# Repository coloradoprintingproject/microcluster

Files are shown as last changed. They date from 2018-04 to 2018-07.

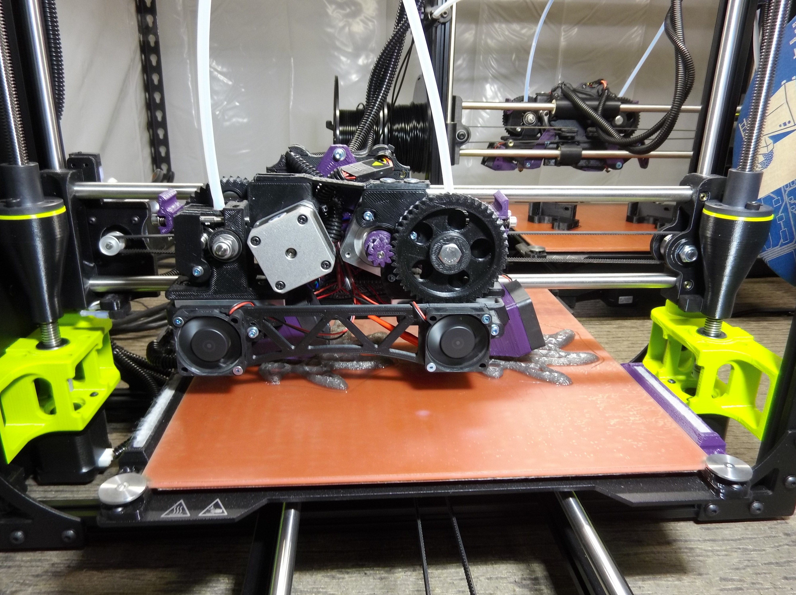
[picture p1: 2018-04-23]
photo/IMG_20180102_165738482.jpg

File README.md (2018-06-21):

This is an obsolete repo for the microcluster project by the Colorado Printing Project, as current development has been moved to notabug.org following the buyout of guthub by microsoft. Unfortunately Github doesn't have a way to make this a mirrior for the active development repo, so please visit https://notabug.org/coloradoprintingproject/microcluster for up to date source.

Everything in this repo is licensed under the GNU GPL v3.0 or CC-BY-SA 4.0.

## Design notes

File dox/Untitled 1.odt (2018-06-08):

The microcluster kit is the easiest way to build up a fitting home for your hard working 3D printers. It is both affordable and highly modular, guaranteeing that you’ll be able to build a 3D printer enclosure that meets your needs without breaking the bank.

While there are lost of printer enclosures currently on the market, you’re pretty much on your own if you want to build a multiple printer enclosure system. Now with the microcluster kit, you can easily build the perfect enclosure system to suit your needs.

Overview:

The microcluster kit system transforms a commonly available shelf into a purpose build, smart enclosure system for 2-6 desktop 3D printers. The modular upgrade system makes it easy to add lights, smart wireless control or even a photo booth setup for professional product photogarphy.

If your current “enclosure” includes cardboard or bubblewrap, it’s time for an upgrade…

The microcluster kit isn’t for everyone. If you’ve only got one printer and are content to stick to PLA printing, you will be able to get along fine without the microcluster. The microcluster kit might be right for you if:

- you have multiple 3D printers
- you are trying to print with higher temperature materials like ABS, Polycarbonate or PEEK
- you’d like some of your desk space back
- your 3D printing has been banished to the garage or basement or any other drafty, dusty place

If this describes you, or if you’ve been thinking of building a better enclosure, read on

Use Cases

Here are just a few of the instances where the microcluster kit could be a life saver:

In house Production

Public use 3D printers

Print service

Printer aficionados

Features and Specifications:

microcluster kit, half and full stack versions:

- Lightweight corrugated polyurethane panels provide excellent thermal insulation and give a professional look to your printer cluster
- Magnetic panel attachment makes the microcluster fast and easy to assemble
- PETG front doors allow you to monitor your print while keeping the enclosure well insulated
- Sliding door setup maximizes space and minimizes drafts when the doors are opened
- Half stack version encloses 24ft^3 of printer space, enough for 1 TAZ and 1 mini or up to 4 LulzBot minis.
- Full stack version encloses 48ft^3 of printer space, enough for 3 TAZ and 3 minis or up to 6 LulzBot minis.

Modular upgrades:

- Lit-kit
  - Easily installs within 5 minutes
  - RGB LED light strip allows color coding of printers, and can be interfaced with may printers as a status indicator
  - Allows for clear webcam monitoring even in a dark room
- Printed Part kit
  - If you’re using the recommended Edsal shelf as a base, this printed part kit will save you upwards of 100hrs of print time for the sliding mechanism
  - designed to print using 0 infill and spiral vase mode, these printed parts maximize any printers efficiency
  - Parts proudly printed out of high quality PLA at our factory in Sheridan, Colorado, USA.
- Octopanel
  - Easy to install and set up, the Octopanel allows you to set up wireless control of your printers withing minutes
  - Designed to work with any desktop printer
  - A portion of every octopanel purchase will go towards funding Octoprint, the open source project making this technology affordable and accessible.
  - The included logitech webcam allows constant monitoring of printing as well as the ability to take timelapses of individual prints.
  - The Octoprint system allows authorized users to access the printers, upload print jobs and monitor them remotely from any web connected device.
- Photo Booth kit
  - Fast and easy to set up, the photo booth kit makes it easy to take professional photographs of you 3D printed products

Documentation & Sources

As with all Colorado Printing Project designs everything is, has been and will continue to be fully open source. All applicable materials are available here: www.github.com/coloradoprintingproject/microcluster

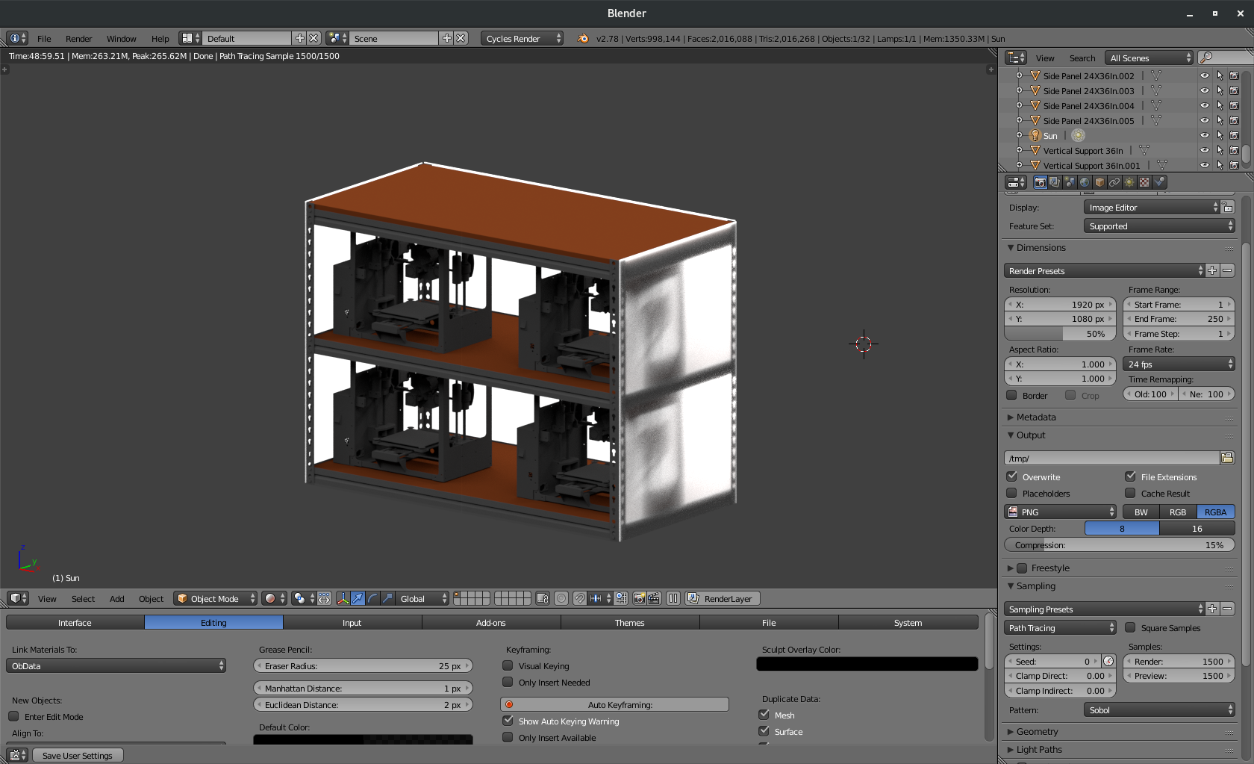
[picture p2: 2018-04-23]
photo/quardaminiclusterunitthing.png

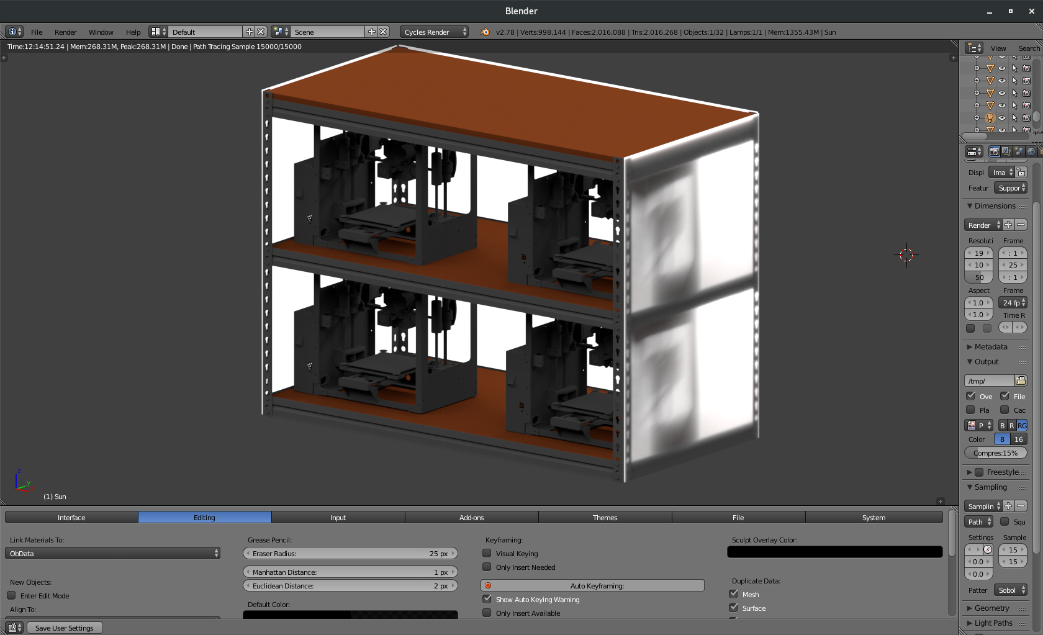
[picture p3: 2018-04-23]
photo/microcluster-render.png

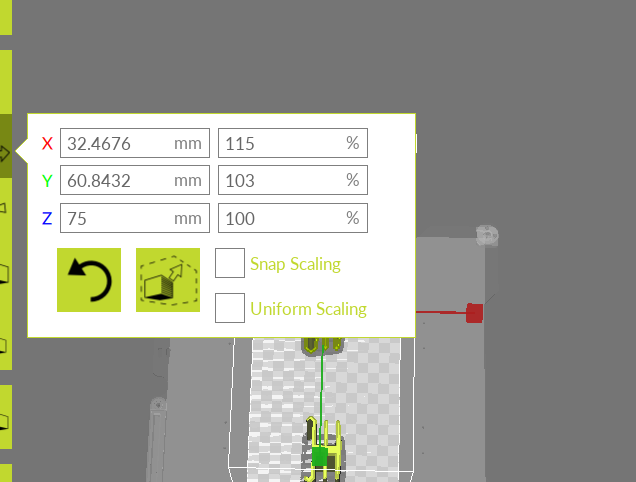
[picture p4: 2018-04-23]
cad/black-pwdrcoat-scale.png

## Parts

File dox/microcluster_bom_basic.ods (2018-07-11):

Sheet: Overview
Product | BOM cost | COGS | Campaign Price | Markup ($) | Markup (%) | Campaign goal | Funding | Profit
Halfstack | $96.70 | $135.70 | $200.00 | $64.30 | 32.15% | 10 | $2,000.00 | $643.00
Fullstack | $151.22 | $195.62 | $300.00 | $104.38 | 34.79% | 5 | $1,500.00 | $521.91
Printed part kit | $43.28 | $69.84 | $100.00 | $30.16 | 30.16% | 8 | $800.00 | $241.27
Octopi kit | $112.00 | $151.96 | $200.00 | $48.04 | 24.02% | 5 | $1,000.00 | $240.19
Light kit | $33.00 | $64.04 | $100.00 | $35.96 | 35.96% | 10 | $1,000.00 | $359.58
Photo Booth kit | $73.00 | $109.65 | $225.00 | $115.35 | 51.27% | 8 | $1,800.00 | $922.80
Creativity unleashed bundle | $2,974.23 | $3,422.84 | $3,999.00 | $576.16 | 14.41% | 2 | $7,998.00 | $1,152.31
Parallel production bundle | $8,866.10 | $10,018.89 | $12,500.00 | $2,481.11 | 19.85% | 1 | $12,500.00 | $2,481.11
 |  |  |  |  | Campaign Funding | $28,598.00
 |  |  |  |  | profit (before taxes) | $6,562.17

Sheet: BOM-microcluster-panel-kit
Copyright 2017 by the Colorado Printing Project, ltd. CC-BY-SA 4.0
Microcluster basic (half-stack) bom
vitamins
what is it? | how many? | where from? | how much? | for all of em?
corrugated plastic sheet, Black, 24x36” | 4 | https://www.signoutfitters.com/CorrugatedPlasticYardSignBlanks-36x24.aspx | $3.05 | $12.20
PETG door panel, 24x35” | 2 | https://www.interstateplastics.com/Petg-Vivak-Sheet-PTGCE~~SH.php?vid=20180423232112-8p-C201804232321-4 | $26.07 | $52.14
Tape | 1 |  | $1.00 | $1.00
magnets | 14 | https://www.kjmagnetics.com/proddetail.asp?prod=R841 | $0.52 | $7.28
Fasteners | 1 | mcmaster | $3.00 | $3.00
Box | 1 | Uline | $7.00 | $7.00
Stickers | 4 | stickergiant | $2.00 | $8.00
fire alarm | 1 | https://www.amazon.com/dp/B01BLQL2DU/ref=twister_B00NF8HKI4?_encoding=UTF8&psc=1 | $6.08 | $6.08
 |  |  | Single qty BOM cost | $96.70
 |  |  | Single Qty BOM with printed parts | $96.70
Microcluster full (full-stack) bom
vitamins
what is it? | how many? | where from? | how much? | for all of em?
corrugated plastic pallet liner, 24x48” | 8 | https://www.signoutfitters.com/CorrugatedPlasticYardSignBlanks-36x24.aspx | $3.05 | $24.40
front clear panel, 24x22” | 6 | https://www.interstateplastics.com/Petg-Vivak-Sheet-PTGCE~~SH.php?vid=20180423232112-8p-C201804232321-4 | $12.53 | $75.18
Tape | 1 |  | $1.00 | $1.00
magnets | 28 | https://www.kjmagnetics.com/proddetail.asp?prod=R841 | $0.52 | $14.56
Fasteners | 1 | mcmaster | $3.00 | $3.00
Box | 1 | Uline | $7.00 | $7.00
Stickers | 10 | stickergiant | $2.00 | $20.00
fire alarm | 1 | https://www.amazon.com/dp/B01BLQL2DU/ref=twister_B00NF8HKI4?_encoding=UTF8&psc=1 | $6.08 | $6.08
 |  |  | Single qty BOM cost | $151.22
 |  |  | Single Qty BOM with printed parts | $151.22

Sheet: printed parts
Copyright 2018 by the Colorado Printing Project, ltd. CC-BY-SA 4.0
Part Name | $ EA | $ Total | Qty | Mass (g) | Mass total (g) | Print time (min) | Print time total (min) | Person time (min) | Person time total (min) | g/hr | $/g
slider guider | $3.37 | $33.67 | 10 | 95 | 950 | 37.5 | 375 | 1.25 | 12.5 | 152 | $0.04
panel handle | $0.60 | $9.61 | 16 | 10 | 160 | 6 | 89 | 1 | 16 | 108 | $0.06
 |  |  |  |  |  |  |  |  |  |  | Average $/g
Total |  | $43.28 | 26 | 105 | 1,110 | 43 | 464 | 2 | 29
Average | $1.98 |  | 13.0 | 53 | 555 | 22 | 232 | 1 | 14 | 130 | $0.05
Labor & equipment costs |  |  | Overhead cost per microcluster | % of total cost
Printer flip rate per hr | $15.00 |  | $7.13 | 16.46%
Printer cost per hr | $0.95 |  | $7.34 | 16.97%
Space cost per hr | $0.10 |  | $0.77 | 1.79%
Electricity cost per hr | $0.04 |  | $0.28 | 0.65% |  |  | 7.73148148148148
Filament cost (PLA) | $25.00 |  | $27.75 | 64.12%
 |  |  | Total printed part cost per microcluster
 |  |  | $43.28

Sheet: panel-kit-funding-calculator
Copyright 2018 by the Colorado Printing Project, ltd. CC-BY-SA 4.0
microcluster half stack funding goal calculator
Batch Qty | 10
BOM | $96.70
Batch Cost (inc labor) | $967.03
Batch Shipping (from mfr) | $15.00
Batch Subtotal | $982.03
Freight on board cost | $98.20
Fulfilment fee (pkg + storage) | $0.00
Est. freight to customer | $25.00
Total COGS less CC + CS fees | $1,232.03
Credit card fee (2.9%+$0.30) | $38.73
CrowdSupply fee (7%) | $86.24
Total COGS | $1,357.00
Total COGS/microcluster | $135.70
Non MOQ COGS | $37.50
Campaign price | $200.00 |  | profit per
 |  |  | 1 | 10 | 100
Min # units | 7 |  | 64.2995366666667 | 642.995366666667 | 6429.95366666667
Funding goal without cushion | $1,400.00
Funding goal with cushion | $1,610.00 | margin | 32.15%
 |  |  | less sales tax | 25.15%
microcluster full stack funding goal calculator
Batch Qty | 10
BOM | $151.22
Batch Cost (inc labor) | $1,512.23
Batch Shipping (from mfr) | $15.00
Batch Subtotal | $1,527.23
Freight on board cost | $152.72
Fulfilment fee (pkg + storage) | $0.00
Est. freight to customer | $25.00
Total COGS less CC + CS fees | $1,777.23
Credit card fee (2.9%+$0.30) | $54.54
CrowdSupply fee (7%) | $124.41
Total COGS | $1,956.18
Total COGS/microcluster | $195.62
Non MOQ COGS | $42.89
Campaign price | $300.00 |  | profit per
 |  |  | 1 | 10 | 100
Min # units | 6 |  | 104.382056666667 | 1043.82056666667 | 10438.2056666667
Funding goal without cushion | $1,800.00
Funding goal with cushion | $2,070.00 | margin | 34.79%
 |  |  | less sales tax | 27.79%

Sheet: printed-part-funding-calculator
Copyright 2018 by the Colorado Printing Project, ltd. CC-BY-SA 4.0
microcluster funding goal calculator
Batch Qty | 10
BOM | $43.28
Batch Cost (inc labor) | $432.76
Batch Shipping (from mfr) | $0.00
Batch Subtotal | $432.76
Freight on board cost | $43.28
Fulfilment fee (pkg + storage) | $5.00
Est. freight to customer | $15.00
Total COGS less CC + CS fees | $632.76
Credit card fee (2.9%+$0.30) | $21.35
CrowdSupply fee (7%) | $44.29
Total COGS | $698.41
Total COGS/printed part kit | $69.84
Non MOQ COGS | $26.56
Campaign price | $100.00
 |  | margin | 30.16%
Min # units | 6
Funding goal without cushion | $600.00
Funding goal with cushion | $690.00

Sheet: octopanel
Copyright 2017 by the Colorado Printing Project, ltd. CC-BY-SA 4.0
 |  | BOM
OctoPanel funding goal calculator |  | what is it? | how many? | where from? | how much? | for all of em?
Batch Qty | 5
BOM | $119.80 | corrugated plastic pallet liner, 24x48” | 1 | https://www.signoutfitters.com/CorrugatedPlasticYardSignBlanks-36x24.aspx | $3.80 | $3.80
 |  | https://www.amazon.com/CanaKit-Raspberry-Complete-Starter-Kit/dp/B0778CZ97B?s=pc | 1 | https://www.amazon.com/CanaKit-Raspberry-Complete-Starter-Kit/dp/B0778CZ97B?s=pc | $70.00 | $70.00
Batch Cost (inc labor) | $599.00 | Box | 1 | Uline | $7.00 | $7.00
Batch Shipping (from mfr) | $5.00 | Stickers | 2 | stickergiant | $2.00 | $4.00
Batch Subtotal | $604.00 | $10 to gina | 1 | patreon | $10.00 | $10.00
Freight on board cost | $120.80 | webcam | 1 | https://www.amazon.com/Logitech-960-000694-Widescreen-designed-Recording/dp/B004FHO5Y6 | $25.00 | $25.00
Fulfilment fee (pkg + storage) | $0.00
Est. freight to customer | $25.00
Total COGS less CC + CS fees | $729.00
Credit card fee (2.9%+$0.30) | $22.64 |  |  |  | Single qty BOM cost | $119.80
CrowdSupply fee (7%) | $51.03
Total COGS | $802.67 |  |  |  | Single Qty BOM with printed parts | $119.80
Total COGS/octopanel | $160.53
Non MOQ COGS | $39.73
Campaign price | $200.00
Min # units | 4
Funding goal without cushion | $800.00
Funding goal with cushion | $920.00
OctoPanel extra brain cost calculator |  | BOM
Batch Qty | 5 | what is it? | how many? | where from? | how much? | for all of em?
BOM | $112.00
Batch Cost (inc labor) | $560.00 | rpi kit | 1 | https://www.amazon.com/CanaKit-Raspberry-Complete-Starter-Kit/dp/B0778CZ97B?s=pc | $70.00 | $70.00
Batch Shipping (from mfr) | $5.00 | Box | 1 | Uline | $3.00 | $3.00
Batch Subtotal | $565.00 | Stickers | 2 | stickergiant | $2.00 | $4.00
Freight on board cost | $113.00 | $10 to gina | 1 | patreon | $10.00 | $10.00
Fulfilment fee (pkg + storage) | $0.00 | webcam | 1 | https://www.amazon.com/Logitech-960-000694-Widescreen-designed-Recording/dp/B004FHO5Y6 | $25.00 | $25.00
Est. freight to customer | $25.00
Total COGS less CC + CS fees | $690.00
Credit card fee (2.9%+$0.30) | $21.51
CrowdSupply fee (7%) | $48.30 |  |  |  | Single qty BOM cost | $112.00
Total COGS | $759.81
Total COGS/octopanel | $151.96 |  |  |  | Single Qty BOM with printed parts | $112.00
Non MOQ COGS | $38.96
Campaign price | $200.00
Min # units | 4
Funding goal without cushion | $800.00
Funding goal with cushion | $920.00

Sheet: light kit
Copyright 2017 by the Colorado Printing Project, ltd. CC-BY-SA 4.0
 |  | BOM
OctoPanel funding goal calculator |  | what is it? | how many? | where from? | how much? | for all of em?
Batch Qty | 10
BOM | $33.00 | corrugated plastic pallet liner, 24x48” | 0 | https://www.signoutfitters.com/CorrugatedPlasticYardSignBlanks-36x24.aspx | $3.80 | $0.00
 |  | LED Strip | 1 | https://www.amazon.com/AMIR-Backlight-Lighting-Waterproof-controller/dp/B073NXF8B7?s=aps | $16.00 | $16.00
Batch Cost (inc labor) | $330.00 | Box | 1 | Uline | $7.00 | $7.00
Batch Shipping (from mfr) | $0.00 | Stickers | 2 | stickergiant | $2.00 | $4.00
Batch Subtotal | $330.00 | Printed parts and fasteners | 1 | coprintpro | $6.00 | $6.00
Freight on board cost | $33.00
Fulfilment fee (pkg + storage) | $0.00
Est. freight to customer | $25.00
Total COGS less CC + CS fees | $580.00
Credit card fee (2.9%+$0.30) | $19.82 |  |  |  | Single qty BOM cost | $33.00
CrowdSupply fee (7%) | $40.60
Total COGS | $640.42 |  |  |  | Single Qty BOM with printed parts | $33.00
Total COGS/lightpanel | $64.04
Non MOQ COGS | $31.04
Campaign price | $100.00
Min # units | 5
Funding goal without cushion | $500.00
Funding goal with cushion | $575.00

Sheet: photo booth kit
Copyright 2017 by the Colorado Printing Project, ltd. CC-BY-SA 4.0
photo booth funding goal calculator |  | Photo-booth bom
Batch Qty | 10 | vitamins |  |  |  |  | printed parts
BOM | $73.00 | what is it? | how many? | where from? | how much? | for all of em?
 |  |  |  |  |  |  | $6.00
Batch Cost (inc labor) | $730.00 | Paper roll | 1 | https://www.amazon.com/Rainbow-Kraft-1369515-Finish-Paper/dp/B0062TMV0A | $23.00 | $23.00
Batch Shipping (from mfr) | $15.00 | lights | 1 | https://www.amazon.com/Lusana-Studio-Photography-Continuous-LNA1004-EYLS949/dp/B076MLFHSN | $29.00 | $29.00
Batch Subtotal | $745.00 | Fasteners | 1 | mcmaster | $3.00 | $3.00
Freight on board cost | $74.50 | Box | 1 | Uline | $10.00 | $10.00
Fulfilment fee (pkg + storage) | $0.00 | Stickers | 1 | stickergiant | $2.00 | $2.00
Est. freight to customer | $25.00
Total COGS less CC + CS fees | $995.00
Credit card fee (2.9%+$0.30) | $31.86
CrowdSupply fee (7%) | $69.65
Total COGS | $1,096.51
Total COGS / photo booth kit | $109.65 |  |  |  | Single qty BOM cost | $67.00
Non MOQ COGS | $35.15
Campaign price | $225.00 |  |  |  | Single Qty BOM with printed parts | $73.00
Min # units | 4 |  | profit per
 |  |  | 1 | 10 | 100
Funding goal without cushion | $900.00 |  | 115.3495 | 1153.495 | 11534.95
Funding goal with cushion | $1,035.00
 |  | margin | 51.27%
 |  |  | less sales tax | 44.27%

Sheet: creativity-unleashed-bundle
Copyright 2018 by the Colorado Printing Project, ltd. CC-BY-SA 4.0
microcluster m2 funding goal calculator
Batch Qty | 5
BOM | $2,974.23 | 3000 | 2 mini 2’s
Labor | $15.00 | 225 | microcluster basic
Batch Cost (inc labor) | $14,946.17 | 250 | photo booth add-on
Batch Shipping (from mfr) | $0.00 | 80 | shelf
Batch Subtotal | $14,946.17 | 100 | light
Freight on board cost | $2,989.23 | 45 | pallet
Fulfilment fee (pkg + storage) | $0.00
Est. freight to customer | $125.00 | 3700
Total COGS less CC + CS fees | $15,571.17
Credit card fee (2.9%+$0.30) | $453.06
CrowdSupply fee (7%) | $1,089.98
Total COGS | $17,114.21
Total COGS/microcluster | $3,422.84
Non MOQ COGS | $433.61
Campaign price | $3,999.00 | margin | 14.41%
 |  | profit per | $576.16
Min # units | 5
Funding goal without cushion | $19,995.00
Funding goal with cushion | $22,994.25

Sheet: parallel-production-bundle
Copyright 2018 by the Colorado Printing Project, ltd. CC-BY-SA 4.0
microcluster tt3 funding goal calculator |  |  |  |  | no printers
Batch Qty | 1 | full stack | 300 | 200 | 300 | 200
BOM | $8,866.10 | 3 TAZ | 7500 | 6375 | 0 | 0
Labor | $0.00 | 2 Twoolhead | 1200 | 900 | 0 | 0
Batch Cost (inc labor) | $8,866.10 | 1 ludicroustruder | 650 | 500 | 0 | 0
Batch Shipping (from mfr) | $100.00 | 3 octopanel | 450 | 400 | 450 | 400
Batch Subtotal | $8,966.10 | 3 lights | 300 | 100 | 300 | 100
Freight on board cost | $8,966.10 | pp | 200 | 75 | 200 | 75
Fulfilment fee (pkg + storage) | $0.00 | shelf | 100 | 85 | 100 | 85
Est. freight to customer | $150.00 |  | 10700 | 8635 | 1350 | 860
Total COGS less CC + CS fees | $9,116.10
Credit card fee (2.9%+$0.30) | $264.67
CrowdSupply fee (7%) | $638.13
Total COGS | $10,018.89
Total COGS/microcluster | $10,018.89
Non MOQ COGS | $1,052.79
Campaign price | $12,500.00 |  | $2,481.11
 |  |  | 19.85%
Min # units | 1
Funding goal without cushion | $12,500.00
Funding goal with cushion | $14,375.00

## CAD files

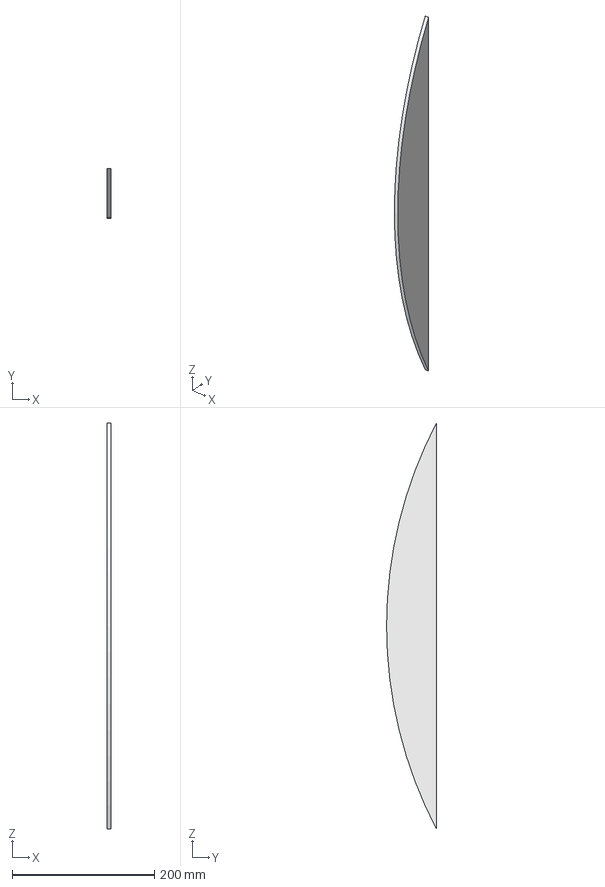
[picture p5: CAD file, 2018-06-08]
cad/full-stack-side-extender.fcstd
6.00 x 70.0 x 570.0 mm

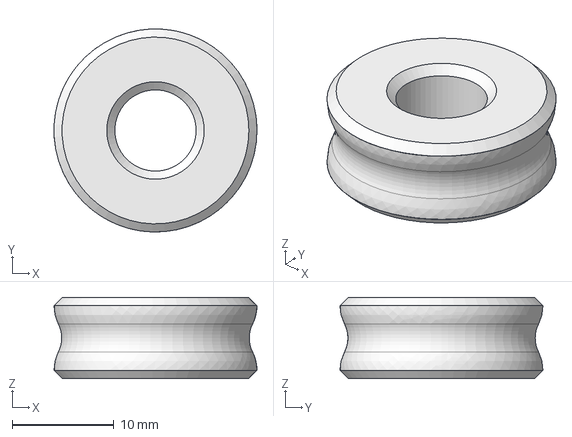
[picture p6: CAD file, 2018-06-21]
cad/panel-handle-type2.fcstd
20.0 x 20.0 x 8.00 mm

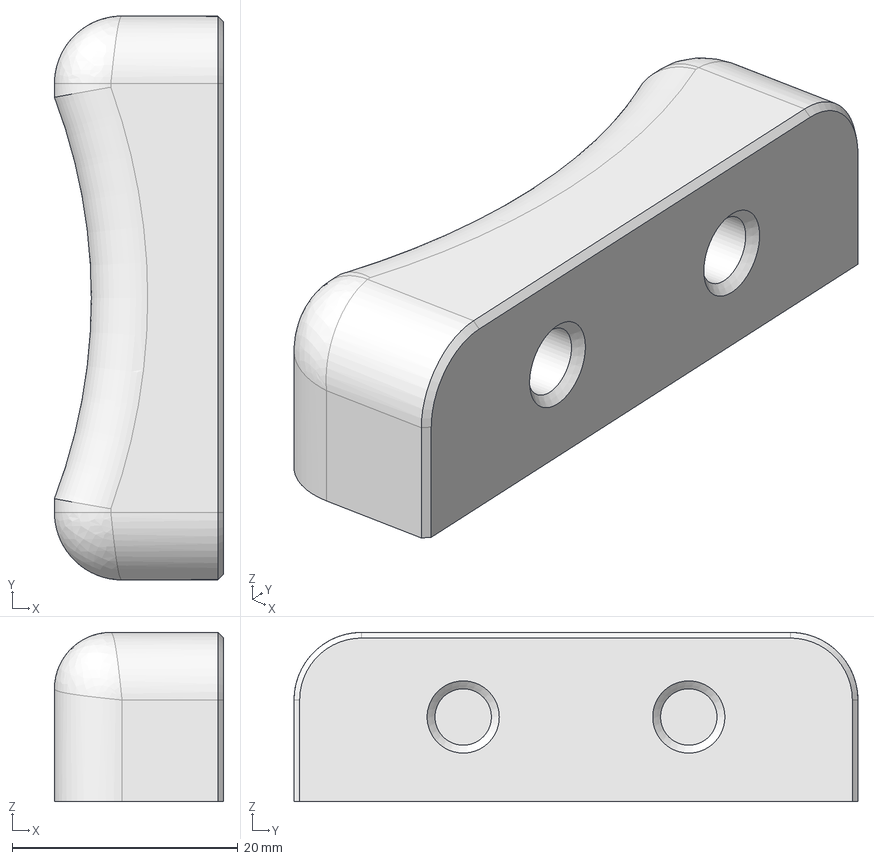
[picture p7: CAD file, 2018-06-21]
cad/halfstack-curve-cover-mount.fcstd
15.0 x 50.0 x 15.0 mm

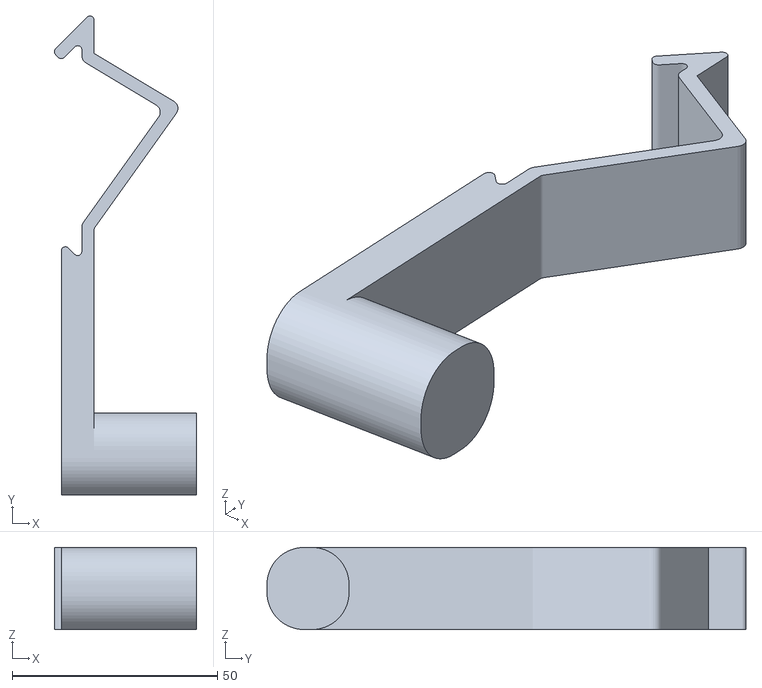
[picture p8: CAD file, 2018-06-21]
cad/roll-holder.stl
34.7 x 116.8 x 20.0

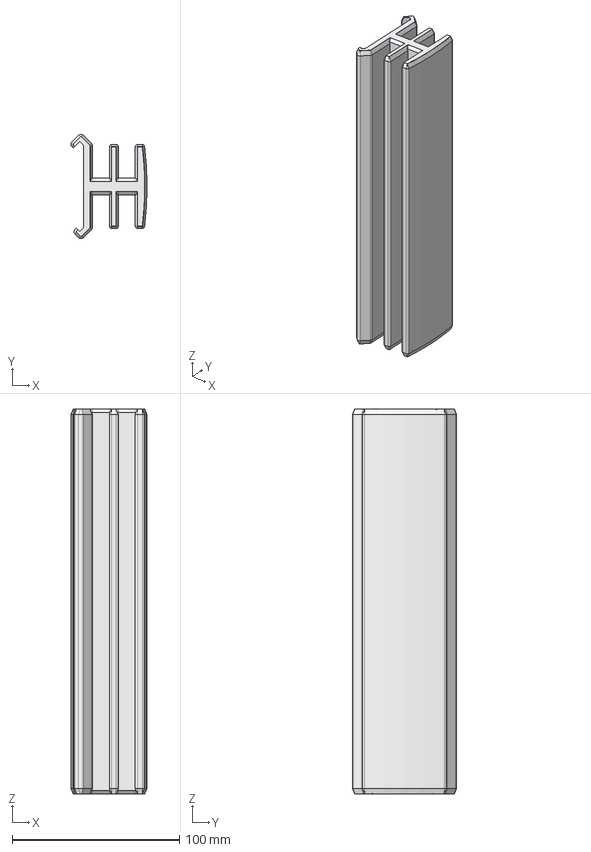
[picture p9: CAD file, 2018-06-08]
cad/slider-guider_4_1.2noz.fcstd
45.5 x 62.3 x 230.0 mm

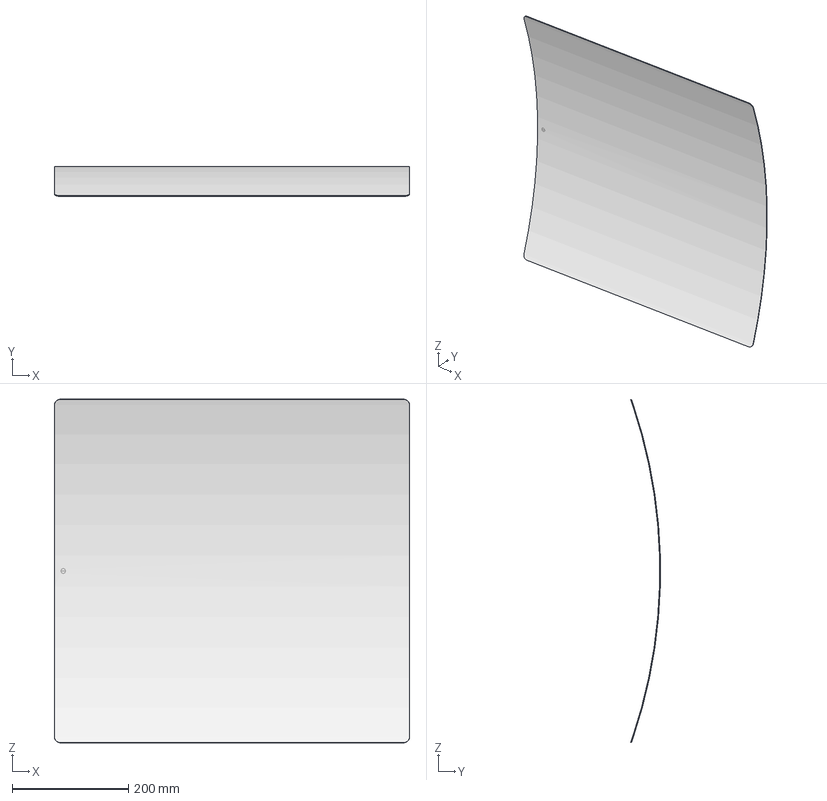
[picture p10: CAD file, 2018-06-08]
cad/24x24x0.060_PETG_panel.fcstd
609.6 x 51.1 x 590.0 mm

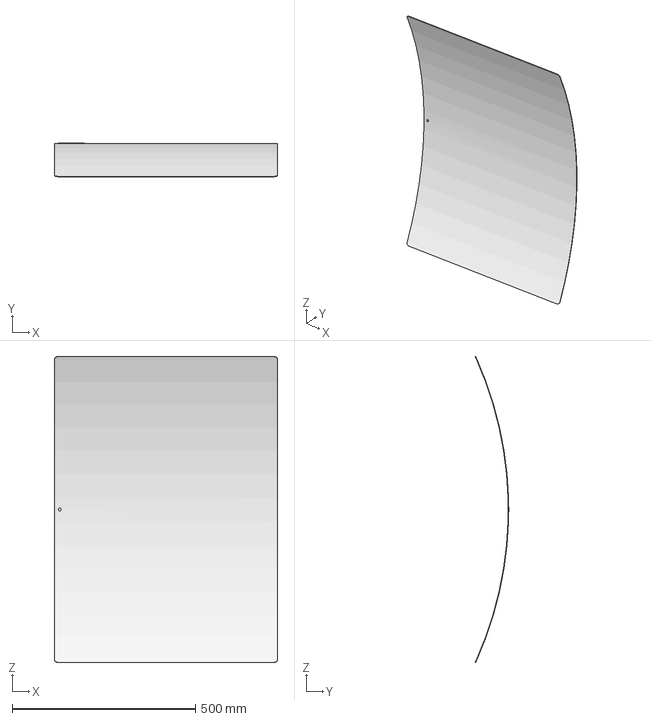
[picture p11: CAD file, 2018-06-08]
cad/24x36x0.060_PETG_panel.fcstd
609.6 x 91.5 x 835.0 mm

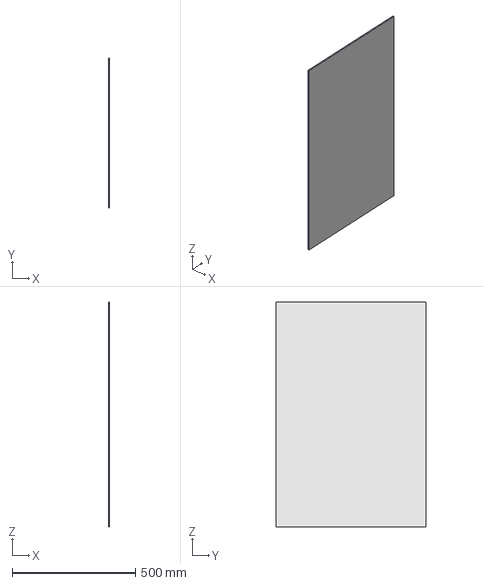
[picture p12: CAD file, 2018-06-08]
cad/24x36in_plastic_panel.fcstd
6.00 x 609.6 x 914.4 mm

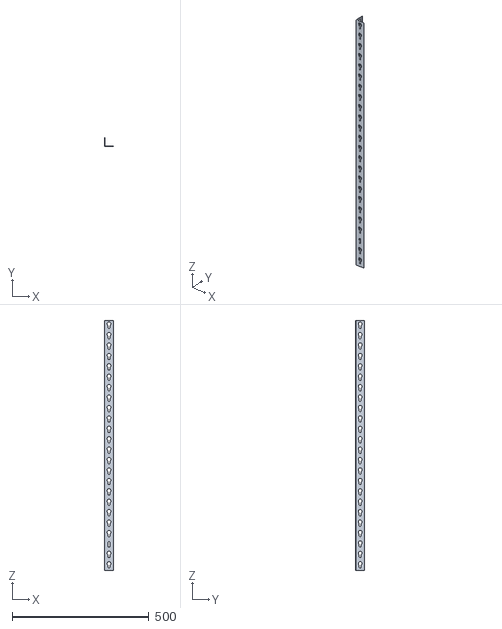
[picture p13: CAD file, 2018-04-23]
cad/vertical_support_36in.stl
31.8 x 33.0 x 914.4

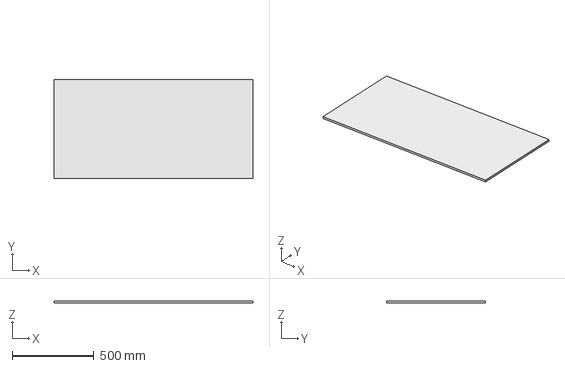
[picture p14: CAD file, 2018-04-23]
cad/shelf_24x48in.fcstd
1219.2 x 609.6 x 12.7 mm

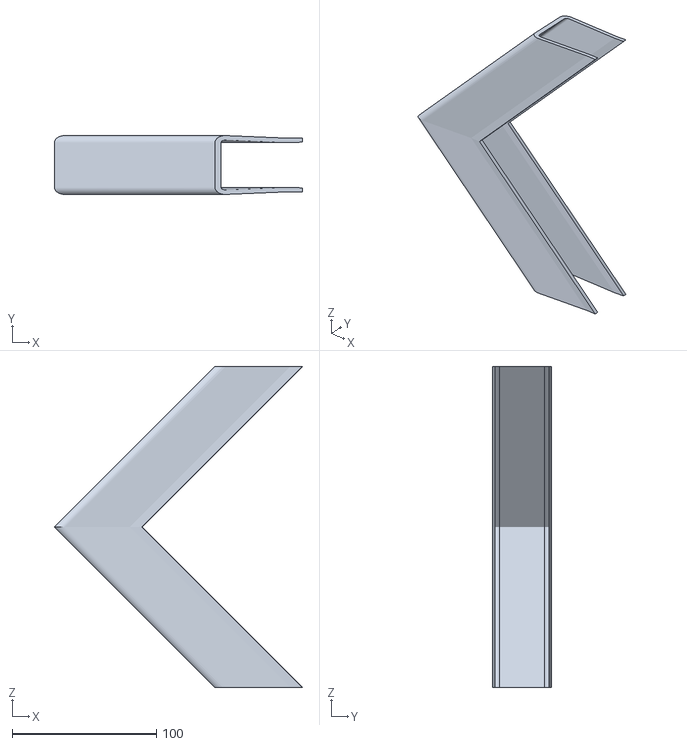
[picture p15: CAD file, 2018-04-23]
cad/spirally-cardboard-corner.stl
171.8 x 40.8 x 222.3

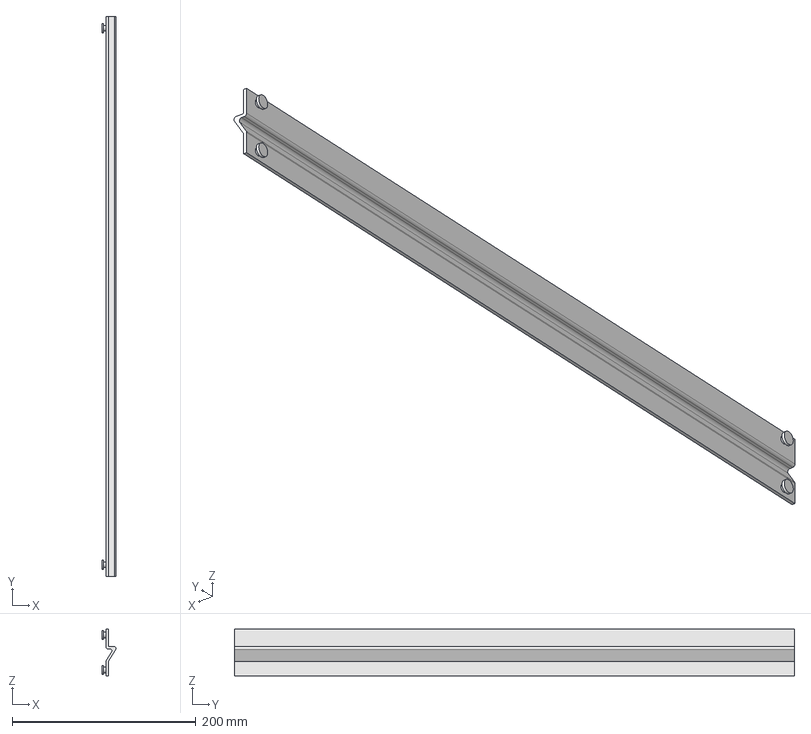
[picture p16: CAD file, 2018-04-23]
cad/horizontal_support_24in.fcstd
15.5 x 609.6 x 50.8 mm

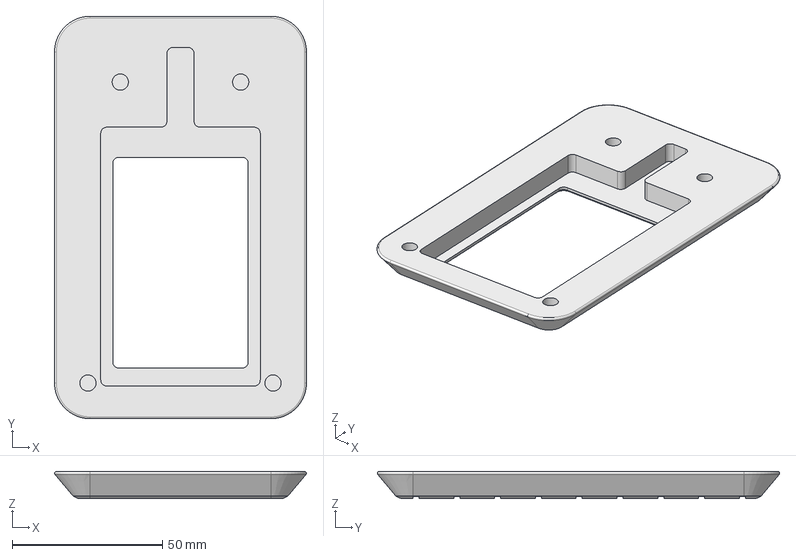
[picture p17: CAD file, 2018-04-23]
cad/LED-remote-bezel-outside.fcstd
83.7 x 133.7 x 9.00 mm

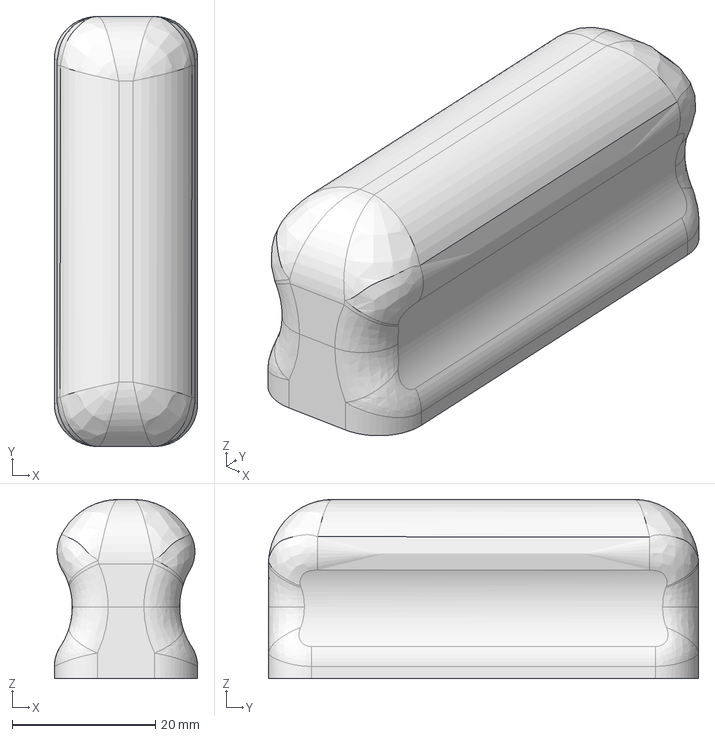
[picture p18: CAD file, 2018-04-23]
cad/panel-handle.fcstd
20.0 x 60.0 x 25.0 mm

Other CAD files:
cad/roller-holder.fcstd
cad/slider-guider_1.2noz.fcstd
cad/side_panel_24x36in.fcstd
cad/shelf_corner.fcstd
cad/24x24x0.060_PETG_panel.stl
cad/24x36in_plastic_panel.stl
cad/24x36x0.060_PETG_panel.stl
cad/LED-remote-bezel-inside.fcstd
cad/LED-remote-bezel-inside.stl
cad/LED-remote-bezel-outside.stl
cad/full-stack-side-extender.stl
cad/halfstack-curve-cover-mount.stl
cad/horizontal_support_24in.stl
cad/horizontal_support_48in.fcstd
cad/horizontal_support_48in.stl
cad/panel-handle-type2.stl
cad/panel-handle.stl
cad/shelf_24x48in.stl
cad/side_panel_24x36in.stl
cad/slider-guider.fcstd
cad/slider-guider.stl
cad/slider-guider_1.2noz.stl
cad/upright_support.fcstd

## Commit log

2018-04-23 new repo created, all files moved over from sandbox
    [LED-remote-bezel-inside.fcstd, LED-remote-bezel-inside.stl, LED-remote-bezel-outside.fcstd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]
2018-06-08 BOM, pledge level and design mods
    [24x24x0.060_PETG_panel.fcstd, 24x24x0.060_PETG_panel.stl, 24x36in_plastic_panel.fcstd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]
2018-06-21 BoM updated and new parts designed for panel kit and photo kit
    [halfstack-curve-cover-mount.fcstd, halfstack-curve-cover-mount.stl, microcluster_bom.ods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]
2018-07-11 bom and images updated
    [microcluster_bom_basic.ods]
